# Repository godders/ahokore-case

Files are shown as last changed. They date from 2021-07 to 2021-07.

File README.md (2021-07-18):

# Ahokore Case

A 3D printable case for Dezli's excellent [Ahokore keyboard](https://github.com/dezlidezlidezli/ahokore).

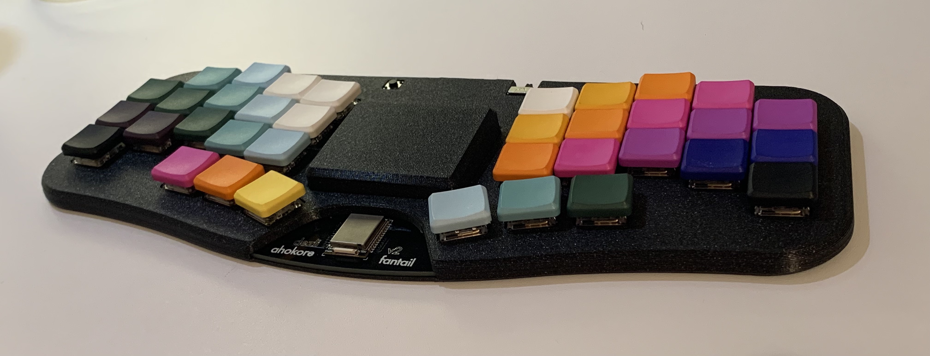
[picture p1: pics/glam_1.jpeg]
case shot angle


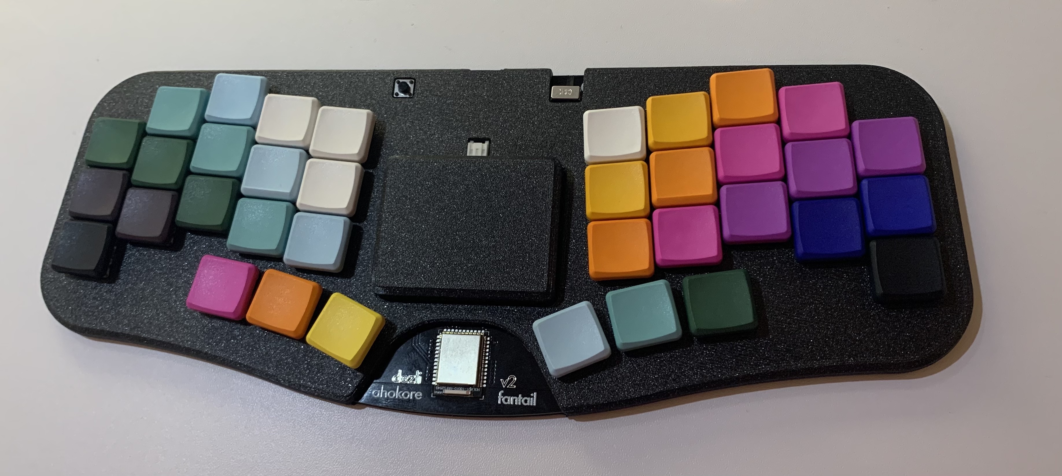
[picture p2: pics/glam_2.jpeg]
case shot top


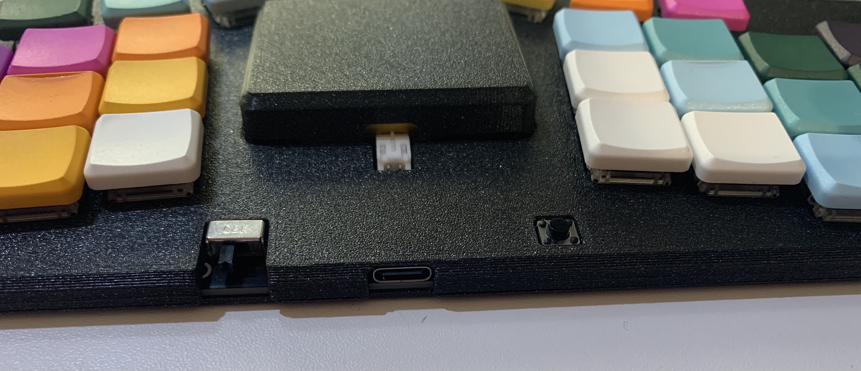
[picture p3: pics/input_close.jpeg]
inputs close up


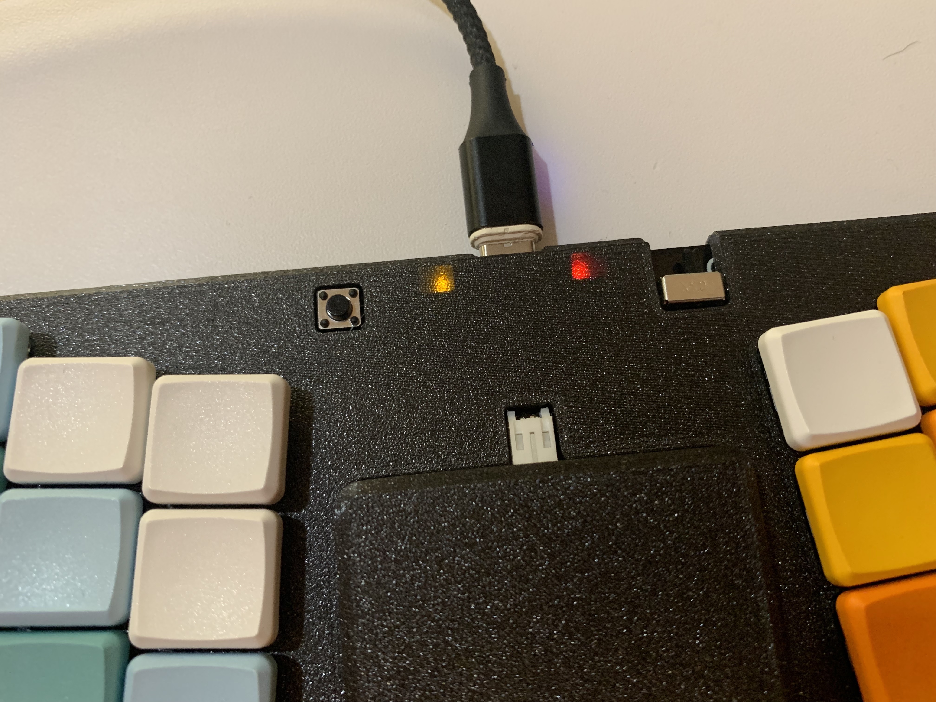
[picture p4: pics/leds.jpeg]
leds


## TL;DR

 * Pick one of the 4 Top case variants - use Ahokore-Top-Tapping-Slipover.stl
   if unsure.
 * Base and battery cover are optional.
 * If using the base you need 10x M2 4-5mm screws, ideally countersunk.
 * If not using the base you need 10x 4mm screws. 5mm may be too long.
 * This is a *tight* fit on most printers. You can probably ignore warnings
   about out-of-bounds toolpaths (at least on a Prusa MK3 printer). Disable
   "loops" if you're worried and the warning should go away.
 * Print at 0.3mm layer height
 * Enable "ironing" when printing the base.

## Case Top

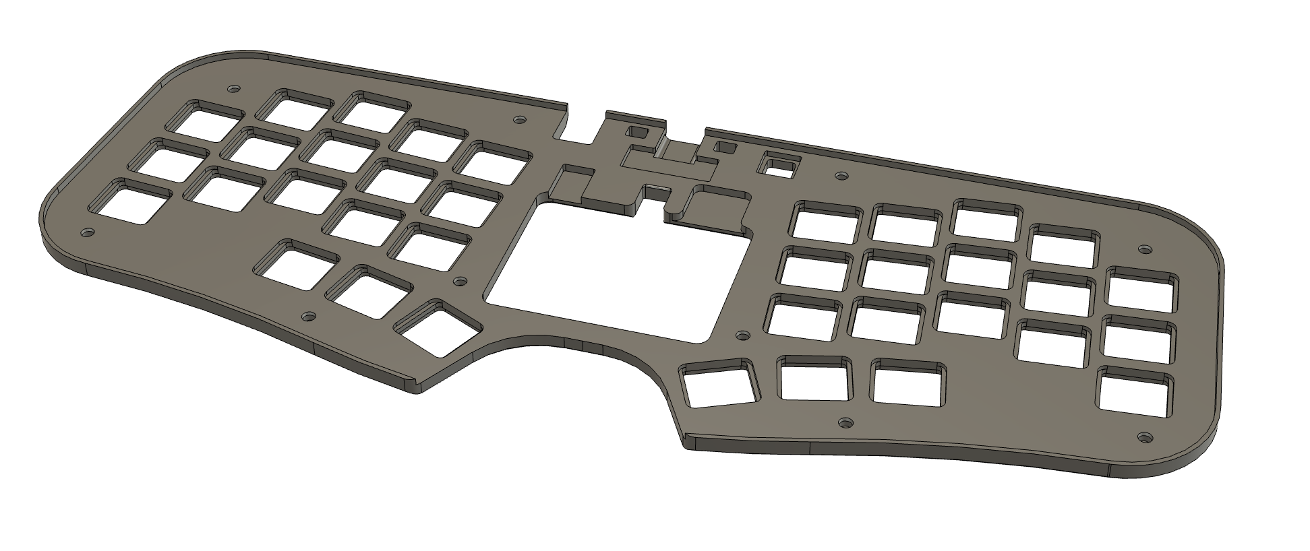
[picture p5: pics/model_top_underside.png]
case top underside


The case top has a couple of different options:

 * Ahokore-Top-Heatset-Plate.stl
 * Ahokore-Top-Heatset-Slipover.stl
 * Ahokore-Top-Tapping-Plate.stl
 * Ahokore-Top-Tapping-Slipover.stl

You only need one of these, here's how to decide which one:

### Heatset or Tapping

The heatset variant has big holes for inserting heatset inserts (which can be
pressed in with a soldering iron).

Supported heatset inserts are M2 3mm wide, up to 3mm long.

These make a much more resilient screw hole but obviously requires you to have
heatset inserts on hand, so there's an alternative variant with smaller holes
that you can screw an M2 screw into directly.

 * Choose "Heatset" if you have heatset inserts
 * Choose "Tapping" if you do not have heatset inserts and want to screw directly into plastic

### Plate or Slipover

The case was originally designed with an integrated plate which makes things a
bit more solid and stable, but obviously means desoldering your switches to
install it. So there's an alternative "slipover" version that will slide over
your switches so you don't need to desolder.

 * Choose "Plate" if you haven't installed your switches yet
 * Choose "Slipover" if you have installed switches and don't want to desolder them

Plate:

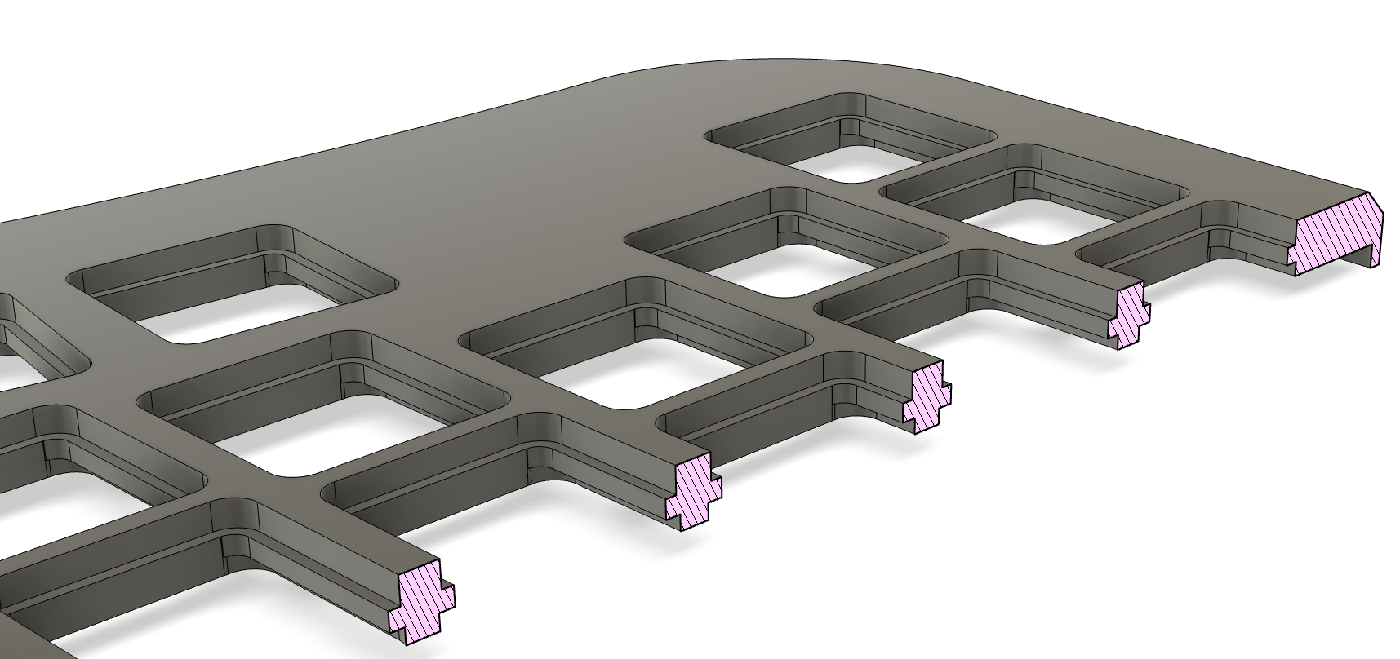
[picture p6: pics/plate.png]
plate cutaway


Slipover:

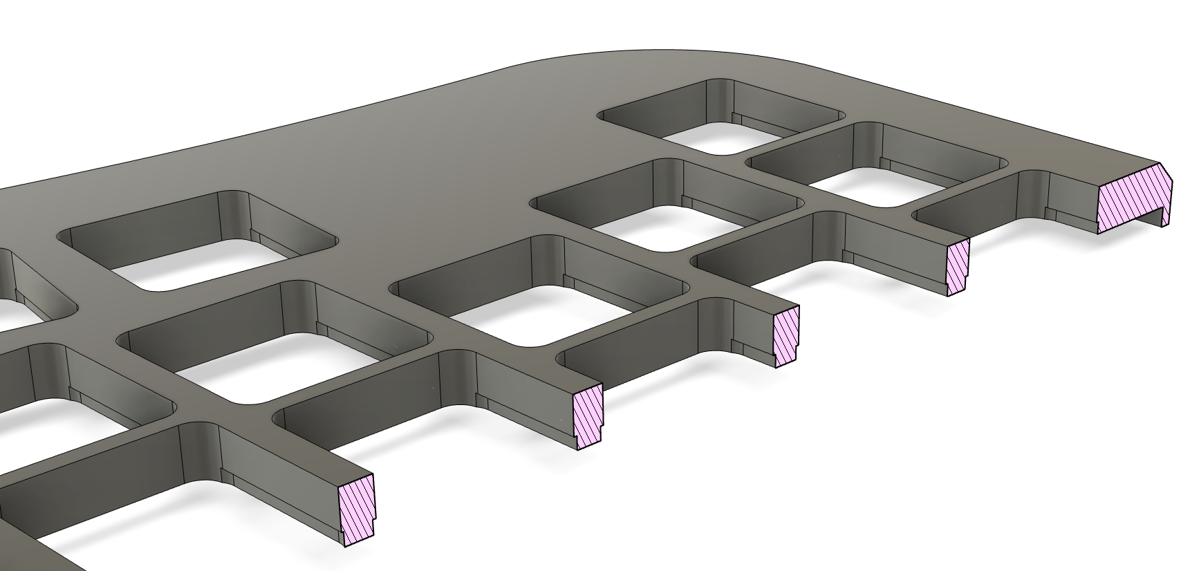
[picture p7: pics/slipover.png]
slipover cutaway


## Base

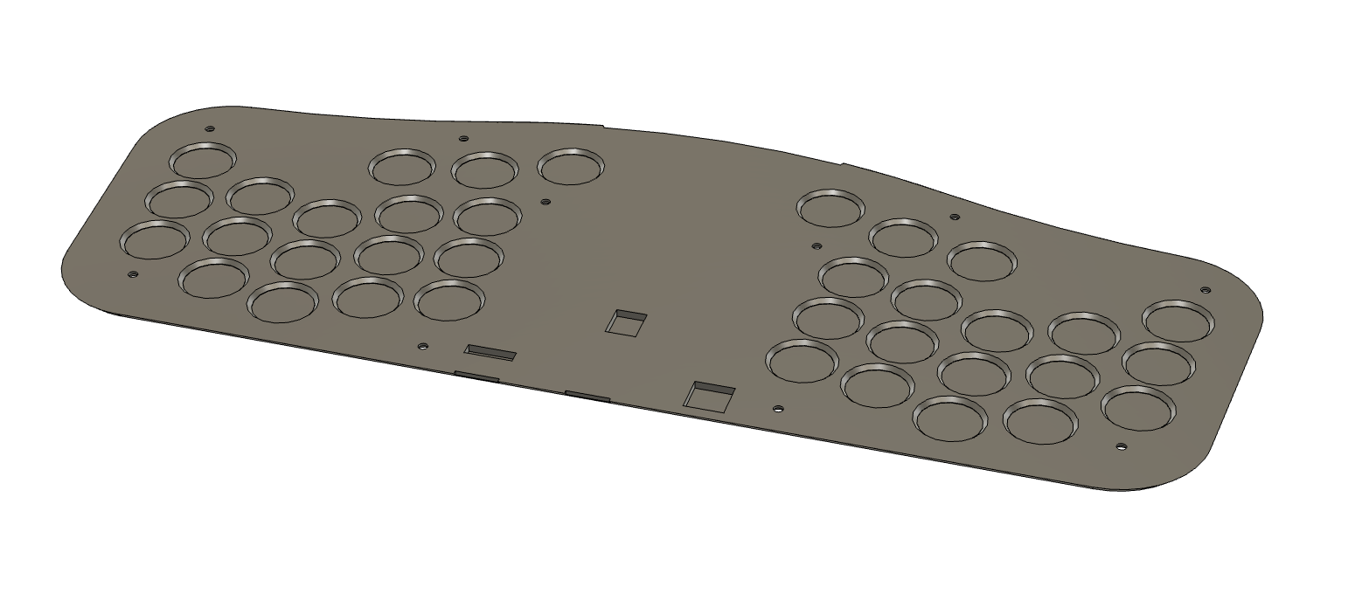
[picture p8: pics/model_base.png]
base


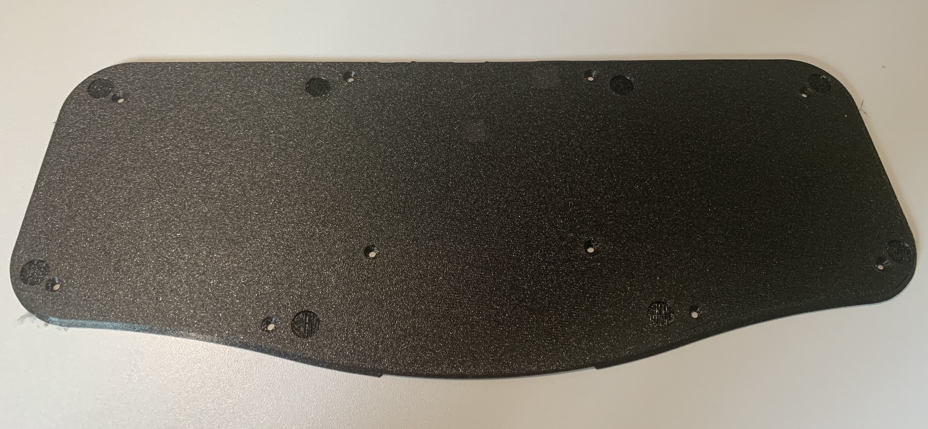
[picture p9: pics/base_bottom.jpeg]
base bottom


Recommended screws are M2 5mm Countersunk (although non-countersunk screws also
work).

## Baseless

The base is optional, and can be omitted if you don't want to cover up the
fantastic PCB artwork, or you want to make it as low profile as possible
(omitting the base saves you about 1.5mm of height).

Here's what the baseless configuration looks like:

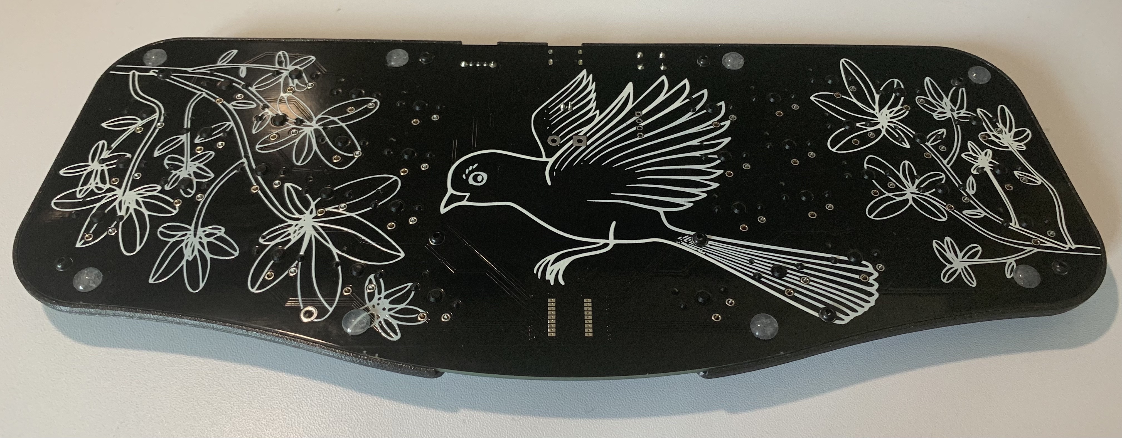
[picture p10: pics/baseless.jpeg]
baseless


(yeah I haven't soldered the switches in that pic!)

If you want to go without the base, then you'll need M2 4mm button head screws
(don't use countersunk screws for this configuration!)

## Battery Cover

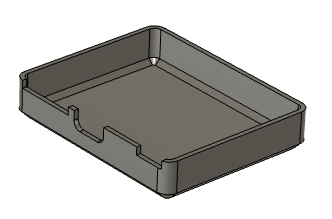
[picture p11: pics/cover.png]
cover


The battery cover is also optional, it's big enough to (just) fit a massive
2400MAh battery, so pretty much anything should fit under there.

Currently it's just push fit into the battery cutout (this probably needs
improvement!)

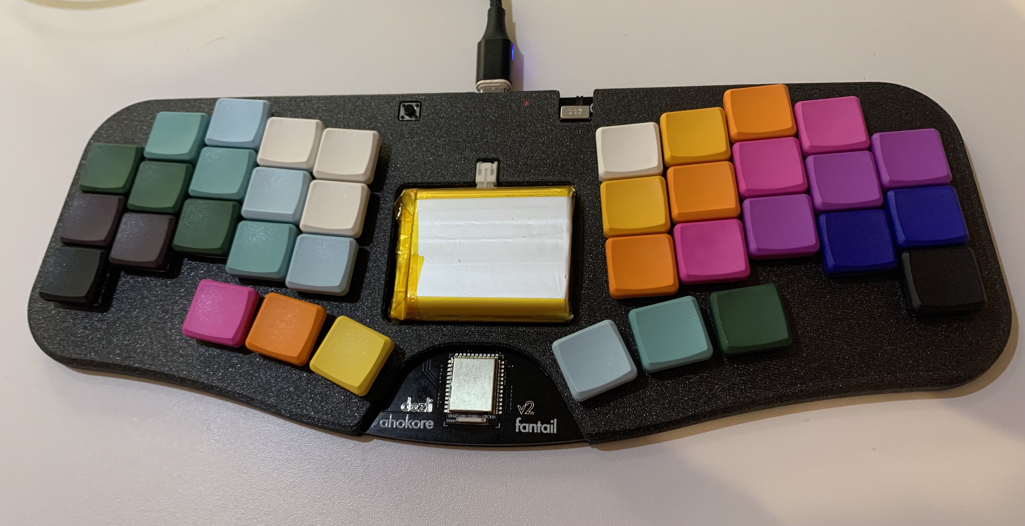
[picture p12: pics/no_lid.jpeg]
no lid


## Printing

So, this thing *only just* fits on my Prusa i3 MK3S bed, and then only at a
very specific angle (of 36°). I've set up the STLs so they have this angle
hard-coded, so you should just be able to print directly.

Even then, if you have "loops" enabled you'll get an error about toolpaths
being out of bounds after slicing.

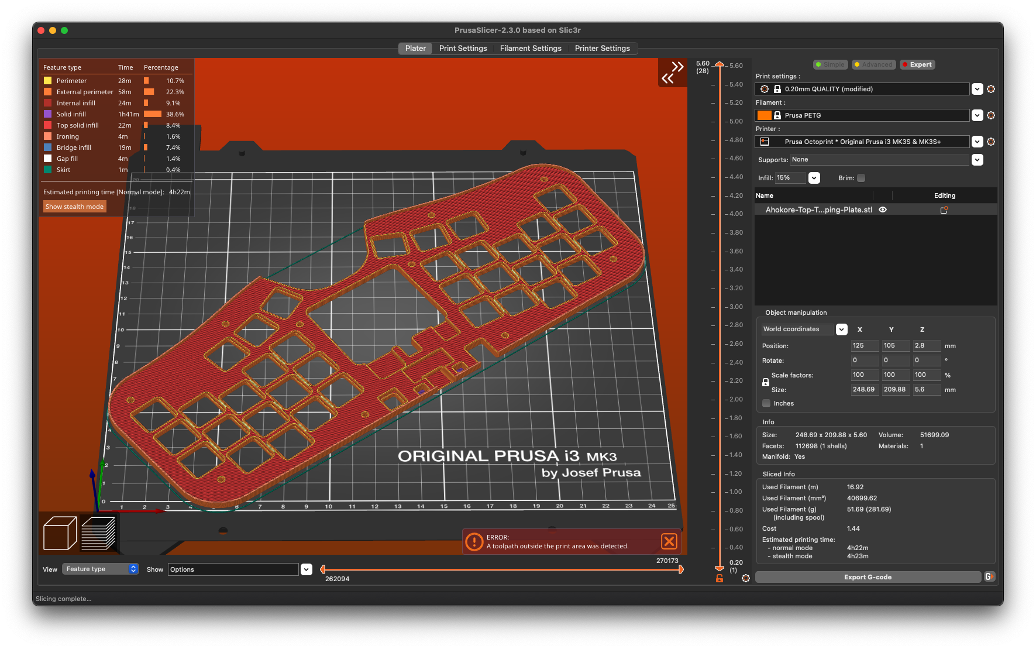
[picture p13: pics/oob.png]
out of bounds warning


You can either disable loops to fix this, or just ignore it. At least on my
setup it prints fine even with loops enabled.

### Top

Aside from the warnings above about toolpaths, there's not much to think about,
I'd recommend printing the top upside-down (that orientation is already set in
the STLs), and at 0.3mm layer height. There doesn't seem to be much reason to go
smaller than that.

### Base

Like the top, the base barely fits on a Prusa's bed, and will generate warnings
if loops are enabled which can usually be ignored.

I'd recommend printing the base with ironing enabled as this will greatly
improve the accuracy of the top surface and will help it to sit flush with
the top without gaps.

Again there's not much reason to go smaller then 0.3mm layer height.

### Battery Cover

Nothing interesting here, just print it upside down to get the best top finish
(as with the other parts, the STLs are already set up in this orientation).

## License

This work is licensed under [CC BY-NC-SA 4.0](https://creativecommons.org/licenses/by-nc-sa/4.0/).
Although please contact me if there's something you want to do that this
license doesn't allow.

(For clarity, I do not consider charging materials and postage to print this for
someone within the community to be "commercial use" and thus perfectly acceptable!)

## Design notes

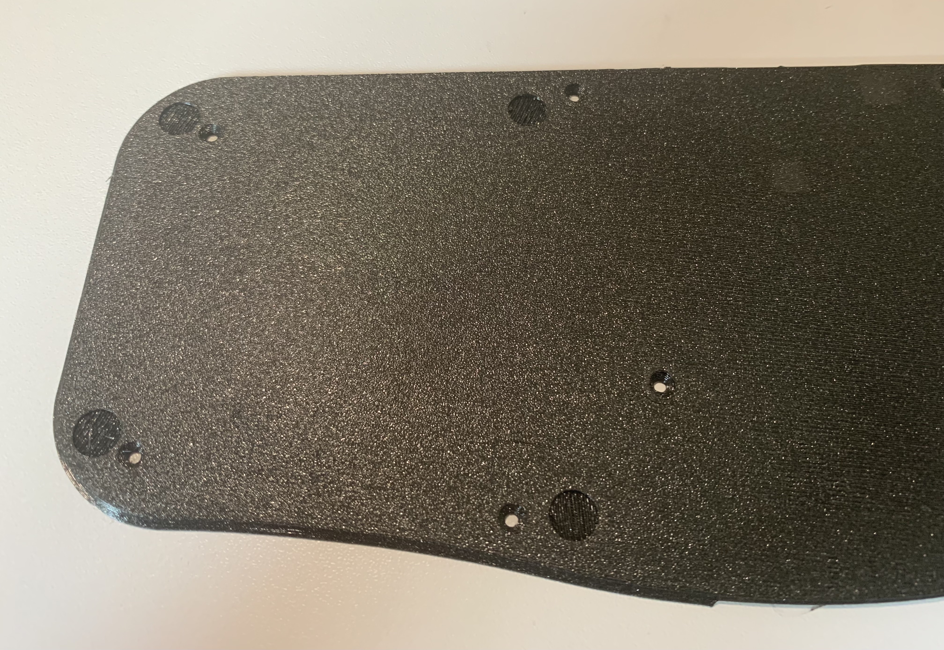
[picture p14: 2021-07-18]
pics/base_close.jpeg

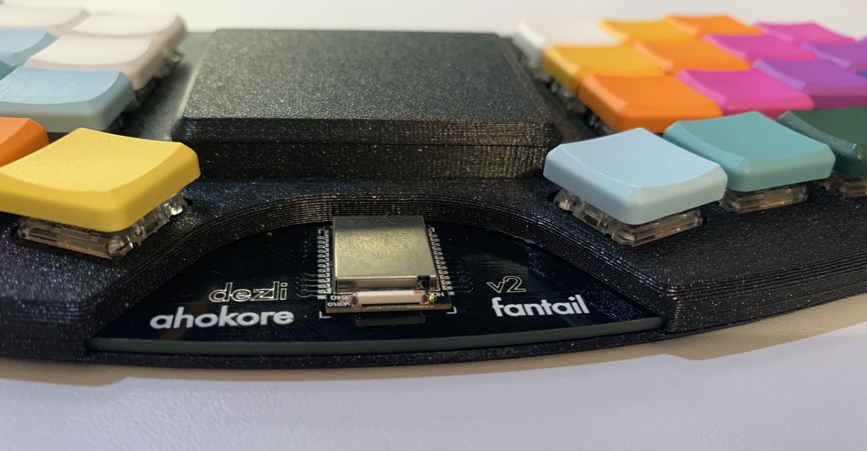
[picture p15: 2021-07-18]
pics/tail.jpeg

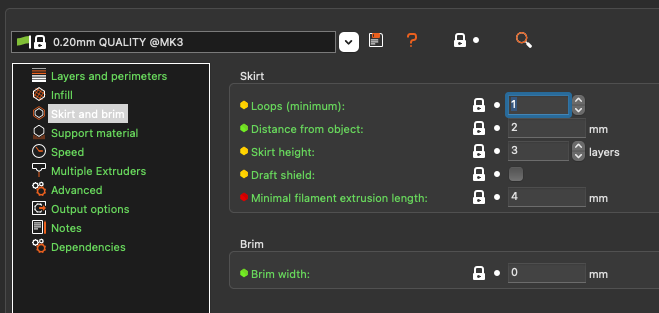
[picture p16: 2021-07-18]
pics/loops.png

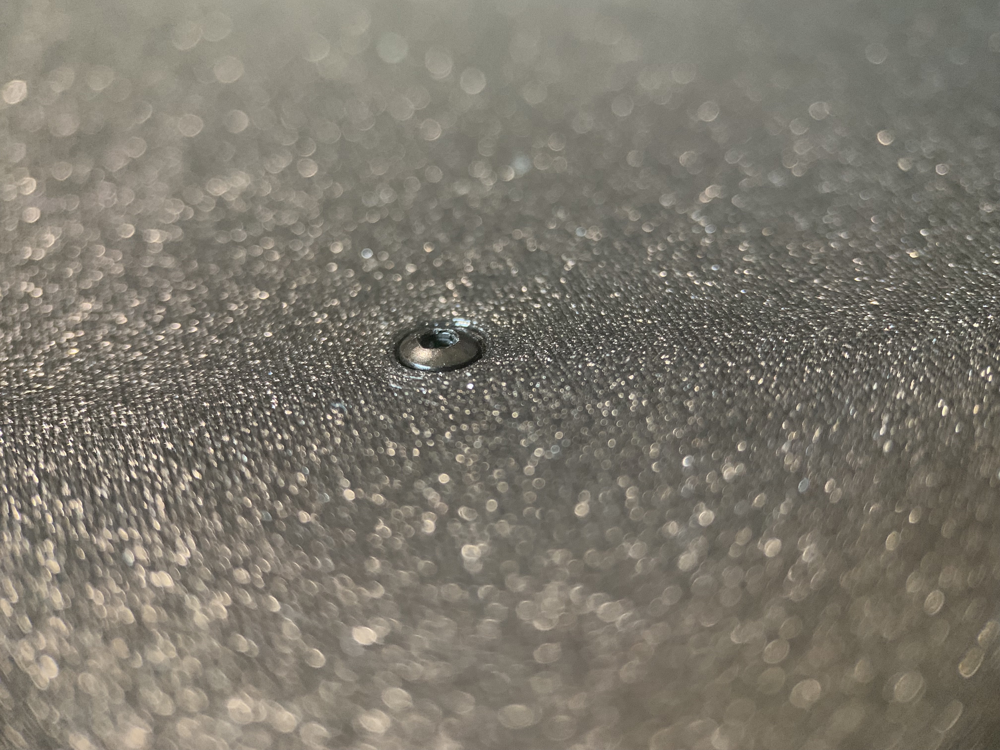
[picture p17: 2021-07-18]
pics/screw.jpeg

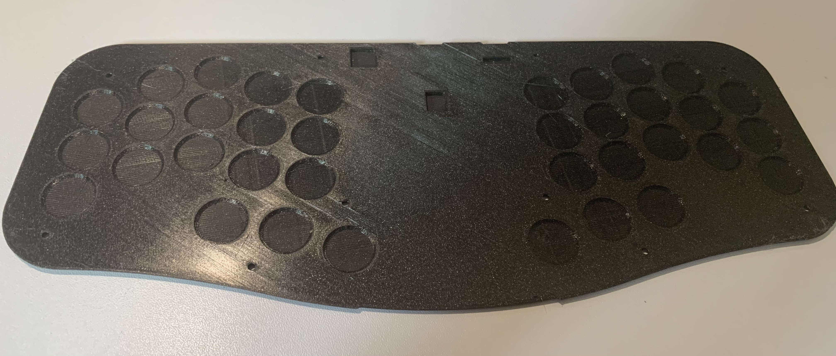
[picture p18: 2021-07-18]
pics/base_top.jpeg

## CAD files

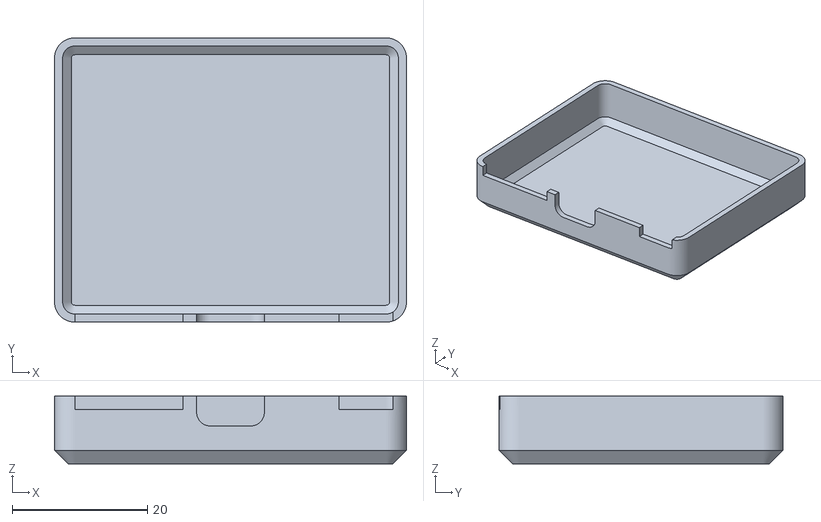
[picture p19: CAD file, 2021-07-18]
Ahokore-BatteryCover.stl
52.0 x 42.0 x 10.0

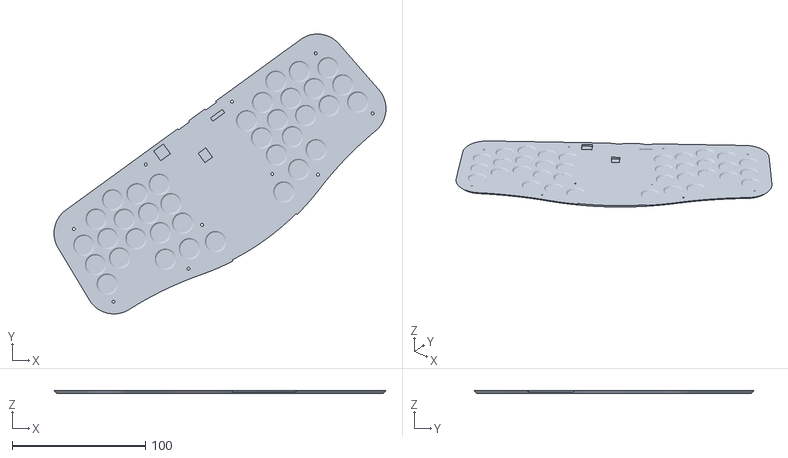
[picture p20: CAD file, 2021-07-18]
Ahokore-Base.stl
248.8 x 209.7 x 2.00
